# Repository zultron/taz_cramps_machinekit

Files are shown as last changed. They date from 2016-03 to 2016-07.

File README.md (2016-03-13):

# LulzBot TAZ 5 Machinekit Retrofit #

This repo contains initial documents for retrofitting a
[LulzBot TAZ 5][1] with [Machinekit][2] running on a
[Beaglebone black][3] with a [CRAMPS][4] V2.2 cape.  It is a work in
progress.

The retrofitted controller will fit in the original TAZ 5 controller
enclosure, and will be pin-compatible with the TAZ 5 harnesses.  The
wired LCD display will be replaced with the [Machineface][5] WiFi-connected
cross-platform remote control GUI.

[1]:  https://www.lulzbot.com/store/printers/lulzbot-taz-5
[2]:  http://machinekit.io
[3]:  http://beagleboard.org/black
[4]:  http://reprap.org/wiki/CRAMPS
[5]:  https://github.com/strahlex/Machineface

## Why? ##

My artist wife needs a 3D printer for her work, and [my company][6]
does, too.  Her friend and colleague loves her TAZ 5, and online
reviews are excellent.  It's open-source hardware, and I'm a founder
of the Machinekit project, an open-source machine control software
project.  3D printers are one type of machine that Machinekit can
control, and It sounded fun to source the parts and build it myself,
and at the same time retrofit the printer with a Beaglebone wearing a
CRAMPS cape (designed by Machinekit project co-founder Charles
Steinkuehler).

Why would anyone else want to do this?  The Beaglebone opens up the
possibilities of running web servers and network control protocols to
operate and monitor the printer remotely, just one example of
integrating sophisticated features not possible with the Arduino.
Machinekit isn't the easy route: while it's been moving ten-plus-ton
steel machines in industrial settings for over two decades, it's new
(like me) to the 3D printer world, and there are still a few remaining
challenges.  The more mature Octoprint may be a lower-effort means of
bringing the Beaglebone's power to the TAZ, and the hardware portion
of this retrofit should be identical.

[6]: http://dovetail-automata.com

## Electronics ##

The CRAMPS cape turns out to be an almost perfect fit for the TAZ-5.
It is designed for 24V, and can handle the TAZ's high power
requirements.  It can drive six motors, has a 15A heated bed FET, as
well as three high-power and two low-power FET outputs for extruders
and fans.  It has more than enough GPIO for limit switches and four
analog thermistor inputs.  To connect the TAZ-5 electronics, aside
from the control box internal harness changes, it also needs a 24V to
5V DC step-down converter to power the Beaglebone and micro blower.  A
board with a LM2596S or MP1584EN costs a few dollars on eBay, and are
tiny.

The motor and low-power FET connectors are Molex KK connectors instead
of the SL connectors the TAZ uses.  I changed the latched SL
connectors to non-latch versions for the limit switch and thermistor
inputs, since they are packed together on the CRAMPS in 2-row .100
headers, and the latch would interfere.  Other connections are
replaced with terminal blocks.

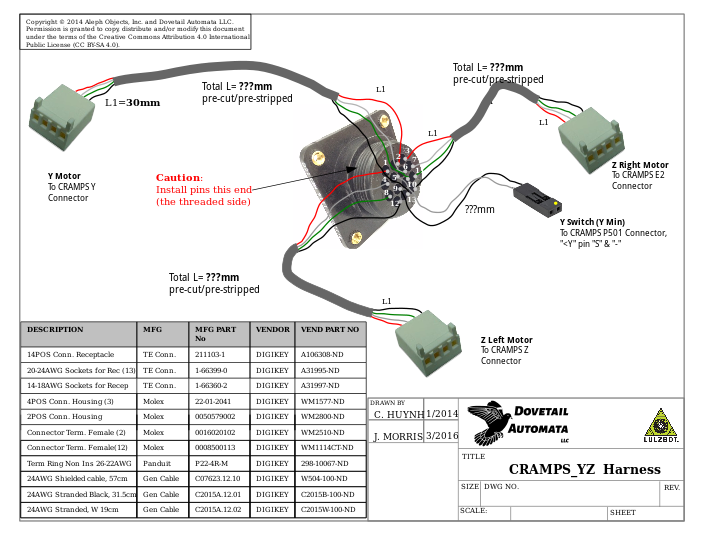
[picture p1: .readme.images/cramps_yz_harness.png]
CRAMPS YZ harness


See the `CRAMPS_*.svg` drawings in this repo for the changes needed to
control box internal harnesses.  If you open in inkscape, you can turn
the `CRAMPS` and `RAMBO` layers on and off to see exactly what
changed.

## Mechanical ##

The CRAMPS cape is about the same size as the RAMBO, but since it sits
atop the Beaglebone, the controller electronics are significantly
taller.  I still expect them to fit the original control box with just
a few millimeters clearance below the fan.

The Beaglebone's mounting holes are, of course, completely different.
A 3D printed part adapts the Beaglebone to the control box's threaded
inserts; see the `bbb_support_bracket.fcstd` FreeCAD model.  The
Beaglebone is attached with M3 flat head socket cap screws from the
bottom, screwing into a stand-off on top of the Beaglebone.  This is
screwed into the control box before the CRAMPS is added on top and
secured with more M3 screws into the stand-offs.  The adapter does not
yet include features to mount the DC step-down converter.

The current adapter cleverly allows access to the SD card through the
original controller box's USB port access hole.  The USB is blocked,
however, which means no WiFi.  I'm still debating whether to expose
the USB port instead (if that's possible) or whether to simply cut new
holes on the CNC mill, including extra holes for buttons, HDMI and
serial console.

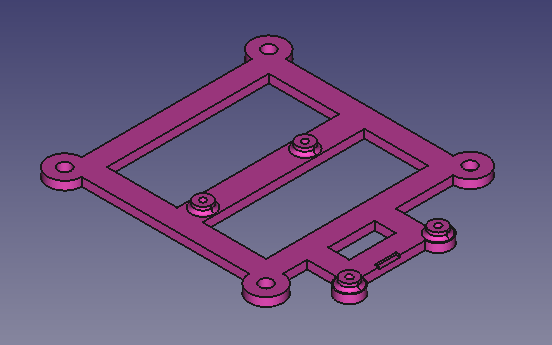
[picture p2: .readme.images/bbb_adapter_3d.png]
Beaglebone adapter


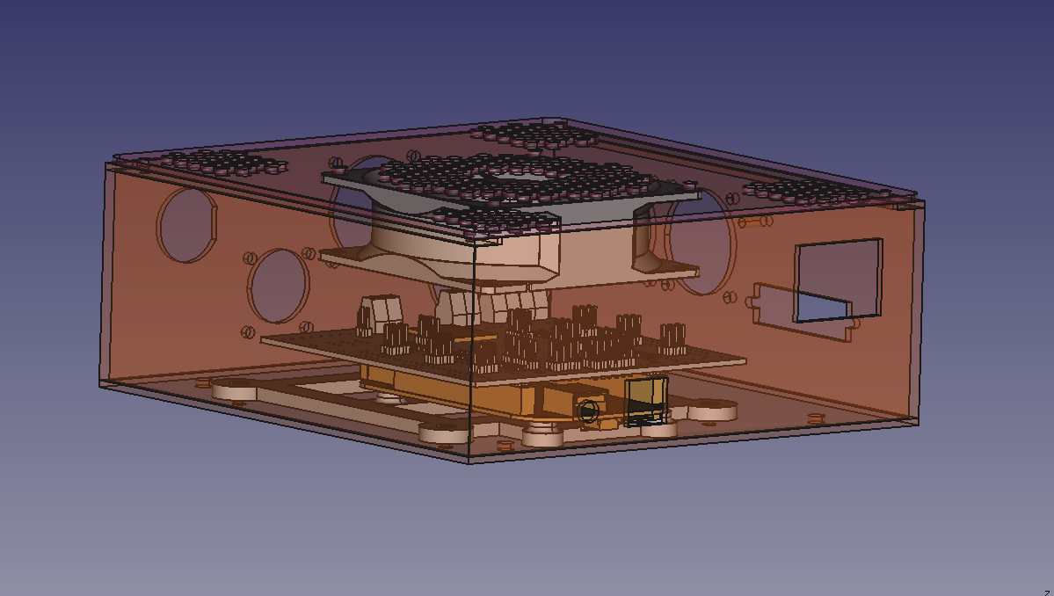
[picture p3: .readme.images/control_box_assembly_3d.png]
Control box assembly


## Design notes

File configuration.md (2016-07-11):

# Axes and geometry

The LulzBot TAZ-5 firmware `Configuration.h` file sets X and Y axes
to 100.5 steps/mm, Z to 1600 steps/mm and E0 at 850 steps/mm.  These
assume 1/16 microstepping, so set `JP201` through `JP206` shunts
accordingly.  Look up the settings for your model of driver, since
they are not all the same.  For example, for 1/16 microstepping,
shunts 1, 2 and 3 should be off, off and on, respectively, for DRV8825
drivers, and all on for A4988 drivers.

# Trimpot adjustment

http://reprap.org/wiki/A4988_vs_DRV8825_Chinese_Stepper_Driver_Boards#Trimpot_adjustment

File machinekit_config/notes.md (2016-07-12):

# Dual extruders

From [flexydually OHAI][fd-ohai]:

- Only one switchable fan
- [Duallie docs][duallie]
- Set temps:
  - Change tool head with `T0` (rear) and `T1` (front)
  - GUI has entry fields for extruder temp and bed (e.g. 240 and 100
    deg. C)
  - Wait until temp hits target, then click 'print' button
- Fan
  - Seems to be turned on per print; like coolant?
  - Apparently needs PWM to control speed?
  - `M106 P0 S255` sets fan 1 PWM on 100%
  - Repetier usage: `M106 P1 T45 H1:2` sets fan 2 to 'thermostatic'
    mode, on when either heater 1 or 2 is above 45 C.
  - `M107` is fan off (deprecated)
  - PWM period [may matter][fan-pwm]
  
After testing:
- Using one stepgen for both motors doesn't work; switching the
  extruder causes a 'joint following error'
- Instead, we probably need two stepgens wired to look like one to
  motion:
  - Two `position-fb` pins are added before going into `motor-pos-fb`
  - The deselected motor `position-cmd` input must be locked, and the
    difference of that and `motor-pos-cmd` coming out must be passed
    into the active `position-cmd` input
  - Probably needs a custom comp.

[fd-ohai]: https://ohai.lulzbot.com/project/lulzbot-taz-flexydually-tool-head-v2-installation/accessories/
[duallie]: http://devel.lulzbot.com/TAZ/accessories/javelin/
[fan-pwm]: https://groups.google.com/forum/#!topic/machinekit/BSLiZSQKoDQ

# 3D printer G code
- G codes at [reprap.org][rro-gcode]; note that 'Machinekit' is
  included in instruction implementation notes
- Some G codes in Machinekit `nc_files/` subdir:
  - `M104` set extruder temp
  - `M106 S255` fan off/on
- Daren Schwenke has a lot of M codes [implemented][ds-mcodes]

[rro-gcode]: http://reprap.org/wiki/G-code
[ds-mcodes]: https://github.com/Arcus-3d/Arcus-3D-M1

# Notes from TAZ configuration
- From the [TAZ firmware][TAZ-fw], `Marlin/Configuration.h`
- Heater limits:
  - They set e.g. `HEATER_0_MINTEMP` to 5, below which assume
    thermistor short/failure, and heater is disabled
  - `HEATER_0_MAXTEMP` is 250, then heater shut off; prevents
    accidental overheating
- Extruder PID terms:
  - Preset for 24V Buda 2.0:  Kp 6, Ki .3, Kd 125
  - `PID_MAX` 74; limits current to nozzle while PID is active (see
    `PID_FUNCTIONAL_RANGE` below); 255=full current
  - `PID_FUNCTIONAL_RANGE` 16; if the temperature difference between
    the target temperature and the actual temperature is more then
    `PID_FUNCTIONAL_RANGE` then the PID will be shut off and the
    heater will be set to min/max.
  - `PID_INTEGRAL_DRIVE_MAX` 70; limit for the integral term
  - `K1` 0.96; smoothing factor within the PID
  - `PID_dT` `((OVERSAMPLENR * 8.0)/(F_CPU / 64.0 / 256.0))` sampling
    period of the temperature routine
  - `EXTRUDE_MINTEMP` 120
- Bed PID terms:
  - Presets for 24V 360W silicone heater from NPH on 3mm borosilicate
    (TAZ 2.2+)
  - `MAX_BED_POWER` 206; limits duty cycle to bed; 255=full current
  - `DEFAULT_bedKp` 20; `DEFAULT_bedKi` 5; `DEFAULT_bedKd` 275
- Geometry:
  - `X_MAX_POS` 298; `Y_MAX_POS` 275; `Z_MAX_POS` 250
- Good stuff about auto bed leveling
- Homing speeds, mm/min:  50*60, 50*60, 8*60
- Axis steps per unit:   100.5,100.5,1600,850; all at 16 microsteps:
  - X/Y gearing: belt is 2mm pitch; gear is 16 teeth; (200 steps/rev)
    / (2mm/tooth * 16 teeth/rev) = 6.25 steps/mm; 1/16 microstepping?;
    Shunts: 1=lo; 2=lo; 3=hi
  - Z gearing: MTSBRK12-420-F7-R8-T9-Q8-S20-E5-FE0-FW7-FY1 screw is
    2mm pitch; (200 steps/rev) / (2mm/rev) = 100 steps/mm; 1/16
    microstepping; Shunts: 1=lo; 2=lo; 3=hi
  - Extruder: M8 hobbed bolt; est. 7mm at hob; gears 9:47; (47/9) *
    (200 steps/rev) / (22mm/rev) = 48 steps/mm; at 1/16 microstepping,
    760 steps/mm; estimate looks reasonable
- Max feedrate, mm/S:  800, 800, 8, 50
- Max accel:  9000,9000,100,10000 "max start speed for accelerated moves"
- Default accel:  500 mm/S^2 all joins max accel for printing moves
- Default retract accel:  3000 mm/S^2 max accel for retracts
- Offset of extruders, mm, X,Y:  E0 0,0; E1 0, -52
- Default jerk, mm/S: XY 8.0; Z 0.4; E 10.0; The speed change that
  does not require acceleration (i.e. the software might assume it can
  be done instantaneously)
- Preheat constants:
  - PLA:  hotend temp 180; hpb temp 50; fan speed 0/255;
  - ABS:  hotend temp 230; hpb temp 85; fan speed 0/255;
- More stuff in `Configuration_adv.h`
- Also `thermistortables.h`

[TAZ-fw]: http://devel.lulzbot.com/TAZ/Holly/software/2014Q3_rB/Marlin/Marlin-2014Q3_rB.tar

# INI file
INI [docs][1]

[1]: http://www.machinekit.io/docs/config/ini_config/

## Steps/mm

From [flexydually OHAI][fd-ohai]:

- X 100.5
- Y 100.5
- Z 1600.0
- Extruder:  configurable, from label
- Retract 3000

## Homing

    HOME_SEARCH_VEL =       -5.0
    HOME_LATCH_VEL =        5.0

# HAL file

- [Pin mappings][2]

[2]: https://drive.google.com/open?id=1xLqDcoijuftPpDJuLmIFQLNdOEL-pKPV24phtdy3Io8

- `hal_temp_bbb` broken; high pin limit needs to be set to 6:

        $ halcmd loadusr -Wn Therm hal_temp_bbb -n Therm -c \
	      04:epcos_B57560G1104,05:epcos_B57560G1104,06:epcos_B57560G1104 -b CRAMPS
        Pin not available

# Testing

## Connector diagram

        Enclosure connector layouts
        Rear:        Top:
        +-----+      +-----+
        | X   | XZ   | X   | Ext1
        |   X | YZ   | X   | Ext2
        | x   | Bed  |   | | D Sub
        |   o | Pwr  |   | | (Empty)
        +-----+      +-----+

        Large 'X' connector pin numbering
             +-+ Large notch
          3 X X X 1
         7 X X X X 4
        11 X X X X 8
         13 X X X 12

        Small 'x' connector pin numbering
           +-+ Large notch
          1 X
         3 X X 2
          4 X

        Pololu header pin numbering
        1 .    . 16
          .    .
          .    .    .
          .    .  | . (Motor conn.)
          .    .  | .
          .    .    .
          .    .
        8 .    . 9

## Power continuity
- Unplug power and printer
- Check continuity between power connector red wires and power switch
- With power switch on, check continuity between power connector red
  wires and:
  - Wire 1:  Motor and extruder power `+` terminals
  - Wire 2:  Bed power `+` terminal
- Repeat with switch off, verifying no continuity
- Check continuity between power connector yellow wires and:
  - Wire 1:  Motor, extruder and system power `-` terminals
  - Wire 2:  Bed power `-` terminal
- 5V checks FIXME
- E2 MOSFET module checks FIXME

## Power voltage
- Unplug wire from 5V converter module OUT+ to CRAMPS 5V system power
- Remove three fuses
- Remove Pololu modules
- Turn enclosure power switch off
- Plug in power supply
- Turn power supply switch on
- Check for 24V DC between power connector red and yellow wires
- Check for 0V DC at motor and bed power `+` terminals
- Turn enclosure power switch on
- Check for 24V DC at motor, extruder and bed power `+` terminals, and
  5V converter module `IN+`
- Check for 5V DC at 5V converter module OUT
- Check for 0V DC at Motor, extruder and bed power `-` terminals
- Turn enclosure power switch off
- Replace three fuses, with 15A fuse in middle holder
- Turn enclosure power switch on
- Check for 24V DC at P401 Bed Heater and P405 E0 power out `+` terminals
- Turn enclosure power switch off
- Plug wire from 5V converter module OUT+ to CRAMPS 5V system power
- Turn enclosure power switch on
- Verify `BB ON` LED is lit
- Check for 5V DC at P404 5V System Power terminal

## Limit switches and motor step/dir

- Setup
  - Disconnect control box cables except for power
  - Remove Pololu/stepper driver boards
  - Power on, boot up, `ssh -X` in
  - `cd` to this directory
  - `linuxcnc CRAMPS.ini &`; wait for Axis GUI to appear
- Test each limit switch:
  - Run `halcmd show signal limit-*-min`, where `*` is `x`, `y` or
	`z`; verify the value is false
  - Short the correct pins on the correct connector
	- X:  XZ connector pins 6 and 10
	- Y:  YZ connector pins 5 and 9
	- Z:  XZ connector pins 9 and 13
  - Rerun the same command; verify the value is true
- Test enable signal and each motor step and dir signals:
  - In Axis GUI, toggle estop and power buttons
  - On the "Manual Control" tab, select the axis to test, `X`, `Y`,
    `Z` or `A`
  - Put a volt meter on `DIR` pin 8 for the CRAMPS Pololu connector
    corresponding to the axis:  `X` = `X`; `Y` = `Y`; `Z` = `Z` and
    `E2`; `A` = extruder (see below); use any ground, or pin 9
  - With the jog increment set to continuous, jog with the `+` and `-`
    buttons, verifying the voltage goes between 0V and 3.3V
  - Put the volt meter on the `Step` pin 7, and verify the voltage
    increases some small amount above 0V; try increasing the "Jog
    Speed" slider for better results
  - For the `A` axis, test as above for the default `E0` pololu socket
    first; then run `halcmd sets extruder.select 1` and repeat for the
    `E1` socket
- Test ESTOP:
  - Remove the shunt from CRAMPS `ESTOP` connector P302; verify that
    the machine has reset in Axis; verify the CRAMPS `ESTOP` LED
    turns on
  - Replace the shunt; in Axis, toggle ESTOP and machine power;
    verify the CRAMPS `ESTOP` LED turns off
- Test machine power signal:
  - Toggle machine power button in Axis; verify `STATUS` LED lights
    with power on
- Test bed and extruder heater FETs:
  - Machine power must be on in Axis
  - Run `halcmd show signal | grep '*.\(temp\|heater\)'`, where `*` is
    `e0`, `e1` or `bed`
  - For E1, run `halcmd sets e1.ini.enable 1`
  - Choose a value much lower than `*.temp.meas`, e.g. -500, and set
    the PID with `halcmd sets *.temp.set -500`
  - Re-run the above `halcmd show signal` command, and verify that the
    `*.heater` signal is 0
  - Verify 24VDC voltage at FET connector `-` terminal
  - Verify FET LED is off
  - Choose a value much higher than `*.temp.meas`, e.g. 500, and set
    the PID with `halcmd sets *.temp.set 500`
  - Re-run the above `halcmd show signal` command, and verify that the
    `*.heater` signal is a positive number
  - Verify 0VDC voltage at FET connector `-` terminal
  - Verify FET LED is on
  - For safety, reset the PID with `halcmd sets *.temp.set 0` after
    testing an individual FET, and `halcmd sets e1.ini.enable 0` after
    testing the E1 FET
- Test bed and extruder heater thermistors: FIXME
- Test extruder fan:
  - Machine power must be on in Axis
  - Run `halcmd sets fan.speed.set 0`
  - Verify 24VDC voltage at E2 FET connector `-` terminal
  - Verify E2 FET LED is off
  - Run `halcmd sets fan.speed.set 255`
  - Verify <24VDC voltage at E2 FET connector `-` terminal
  - Verify E2 FET LED is on (perhaps pulsing)

# Bring up
- Set microstepping shunts to 16V for each motor:
  - For DRV8825, shunts 1 and 2 should be off; shunt 3 should be on
- Set Pololu current limit trimpot
  - Disconnect motors and power up controller
  - Measure Vref at driver current limit trim pot
  - Adjust trim pot according to driver and motor rated current
    - Example motor current ratings:
      - Stock TAZ SY42STH47-1504A motors [rated 1.5A][taz-motor-ds]
	  - 17HS16-2004S1 motors rated 2A
    - Determine how to set Vref for your driver
	  - [DRV8825][pololu-drv8825]:  current = 2 * Vref; Vref = 0.75V
        for stock TAZ motors
    - Set current; [helpful video][pololu-trim-vid]
      - Attach volt meter to screwdriver and adjust trim pot to Vref

[taz-motor-ds]: https://download.lulzbot.com/AO-100/hardware/electronics/spec_sheets/SY42STH47-1504A_stepperMotors.pdf
[pololu-trim-vid]: https://www.youtube.com/watch?v=89BHS9hfSUk
[pololu-drv8825]: https://www.pololu.com/product/2133

# Machineface
- Daren's [configs][ds-mcodes]; see `Arcus-3D-M1.qbs`, `launcher.ini`,
  `run.py`, `storage.ini`

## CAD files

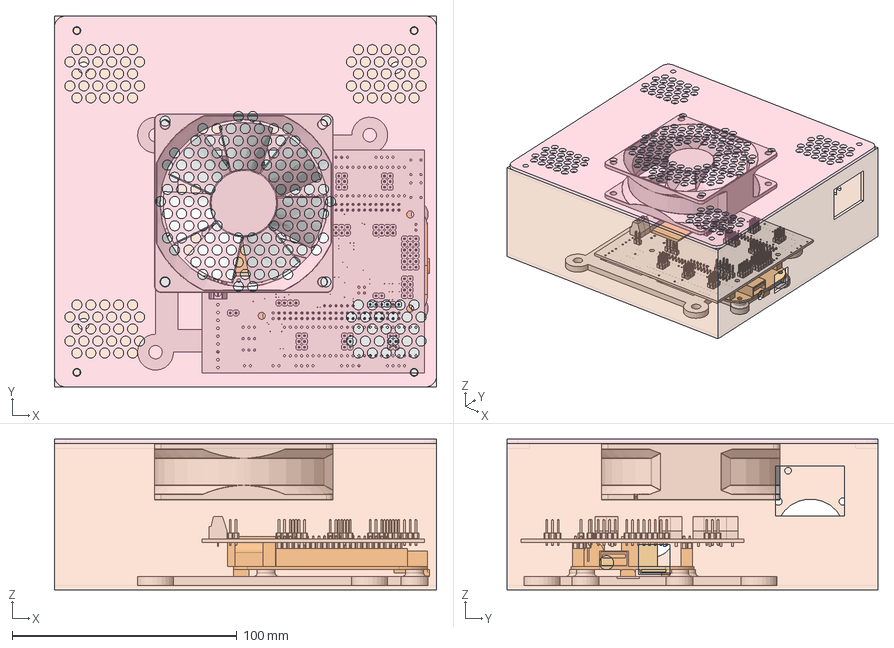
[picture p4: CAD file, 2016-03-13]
mechanical/control_box_assembly.fcstd
170.0 x 165.0 x 67.0 mm
control_box_enclosure
beaglebone_black
bbb_support_bracket
CRAMPS_3D_step1_01
_0mm_fan_igs1_01
electronics_cover_revA_fc0_1_01

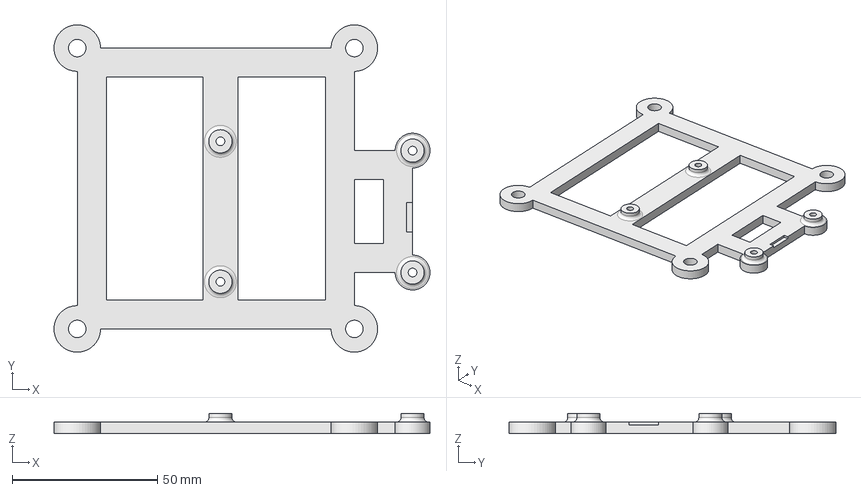
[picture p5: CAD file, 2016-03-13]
mechanical/bbb_support_bracket.fcstd
129.2 x 112.5 x 7.00 mm

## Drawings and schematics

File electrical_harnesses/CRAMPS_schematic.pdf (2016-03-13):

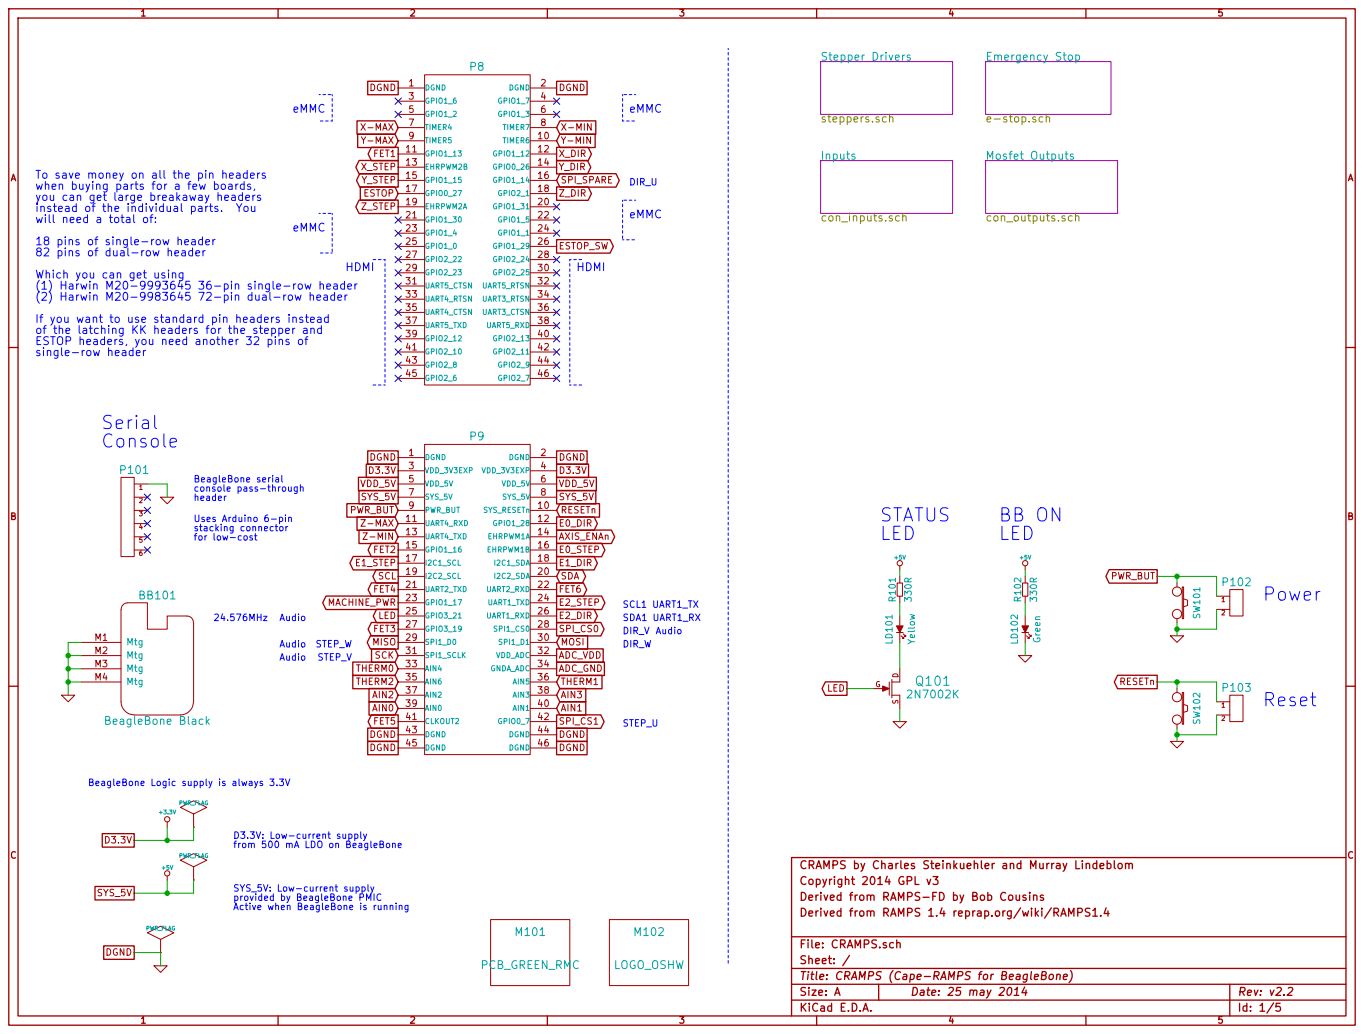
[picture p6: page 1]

To save money on all the pin headers
when buying parts for a few boards,
you can get large breakaway headers
instead of the individual parts. You will need a total of: 18 pins of single-row header

82 pins of dual-row header
Which you can get using
(1) Harwin M20-9993645 36-pin single-row header
(2) Harwin M20-9983645 72-pin dual-row header
If you want to use standard pin headers instead
of the latching KK headers for the stepper and
ESTOP headers, you need another 32 pins of

BeagleBone Logic supply is always 3.3V

D3.3V: Low-current supply
from 500 mA LDO on BeagleBone

CRAMPS by Charles Steinkuehler and Murray Lindeblom
Copyright 2014 GPL v3
Derived from RAMPS-FD by Bob Cousins
Derived from RAMPS 1.4 reprap.org/wiki/RAMPS1.4

provided by BeagleBone PMIC
Active when BeagleBone is running

File: CRAMPS.sch
Sheet: /
Title: CRAMPS (Cape-RAMPS for BeagleBone)
KiCad E.D.A.

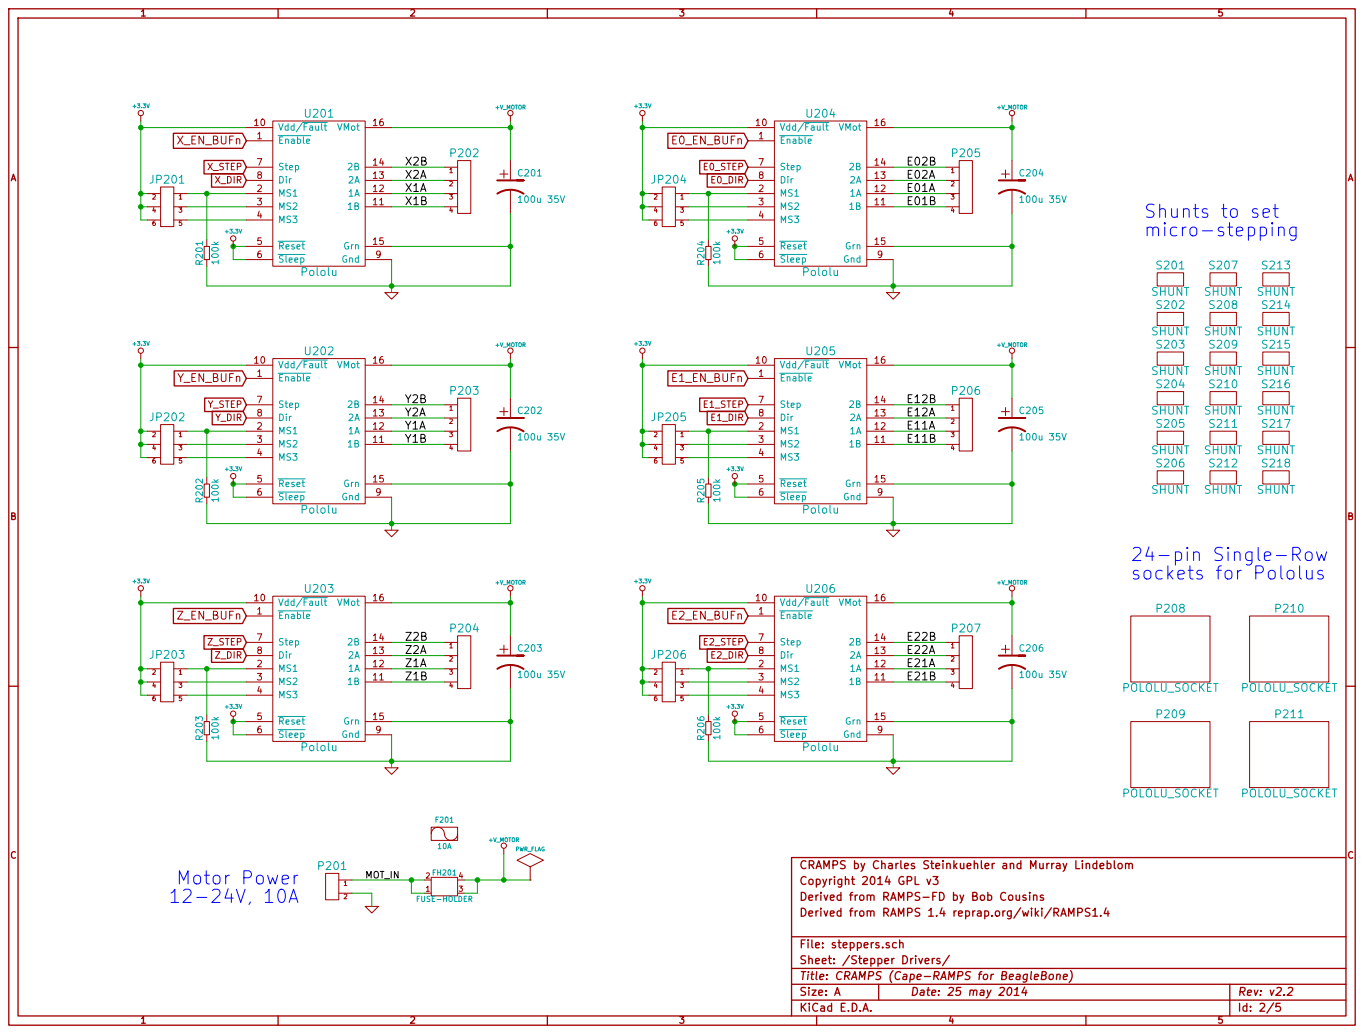
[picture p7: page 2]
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

File: steppers.sch
Sheet: /Stepper Drivers/
Title: CRAMPS (Cape-RAMPS for BeagleBone)

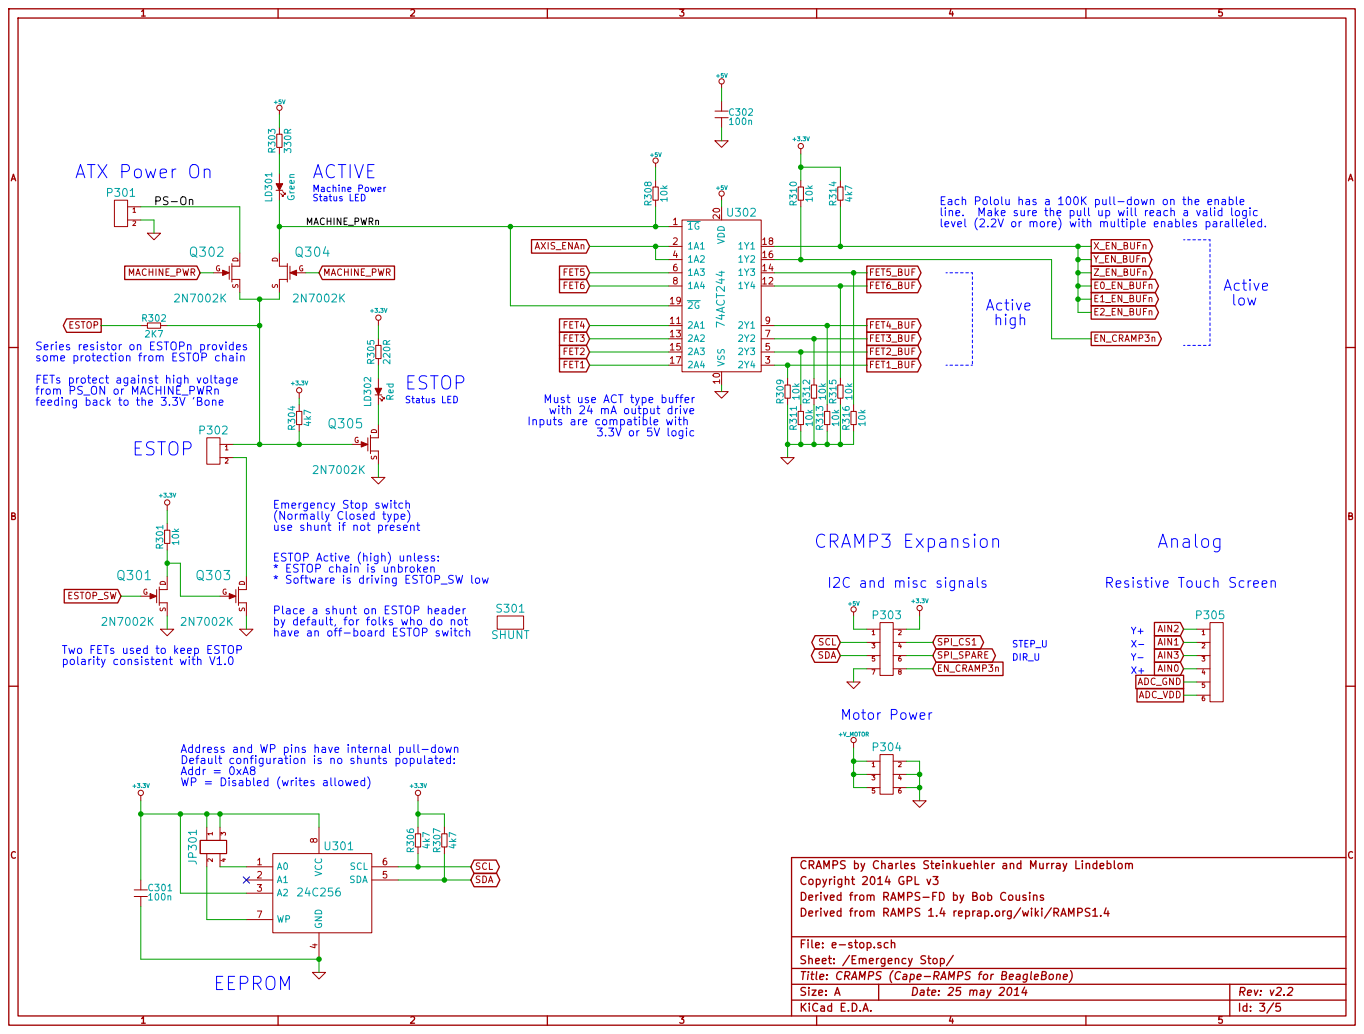
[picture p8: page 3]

Each Pololu has a 100K pull-down on the enable
line. Make sure the pull up will reach a valid logic

level (2.2V or more) with multiple enables paralleled. ESTOP

Series resistor on ESTOPn provides
some protection from ESTOP chain
FETs protect against high voltage
from PS_ON or MACHINE_PWRn
feeding back to the 3.3V 'Bone

Must use ACT type buffer
with 24 mA output drive
Inputs are compatible with

ESTOP Active (high) unless:
* ESTOP chain is unbroken
* Software is driving ESTOP_SW low

Place a shunt on ESTOP header
by default, for folks who do not
have an off-board ESTOP switch

Two FETs used to keep ESTOP
polarity consistent with V1.0

100n Address and WP pins have internal pull-down
Default configuration is no shunts populated: Addr = 0xA8 WP = Disabled (writes allowed)

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

File: e-stop.sch
Sheet: /Emergency Stop/
Title: CRAMPS (Cape-RAMPS for BeagleBone)

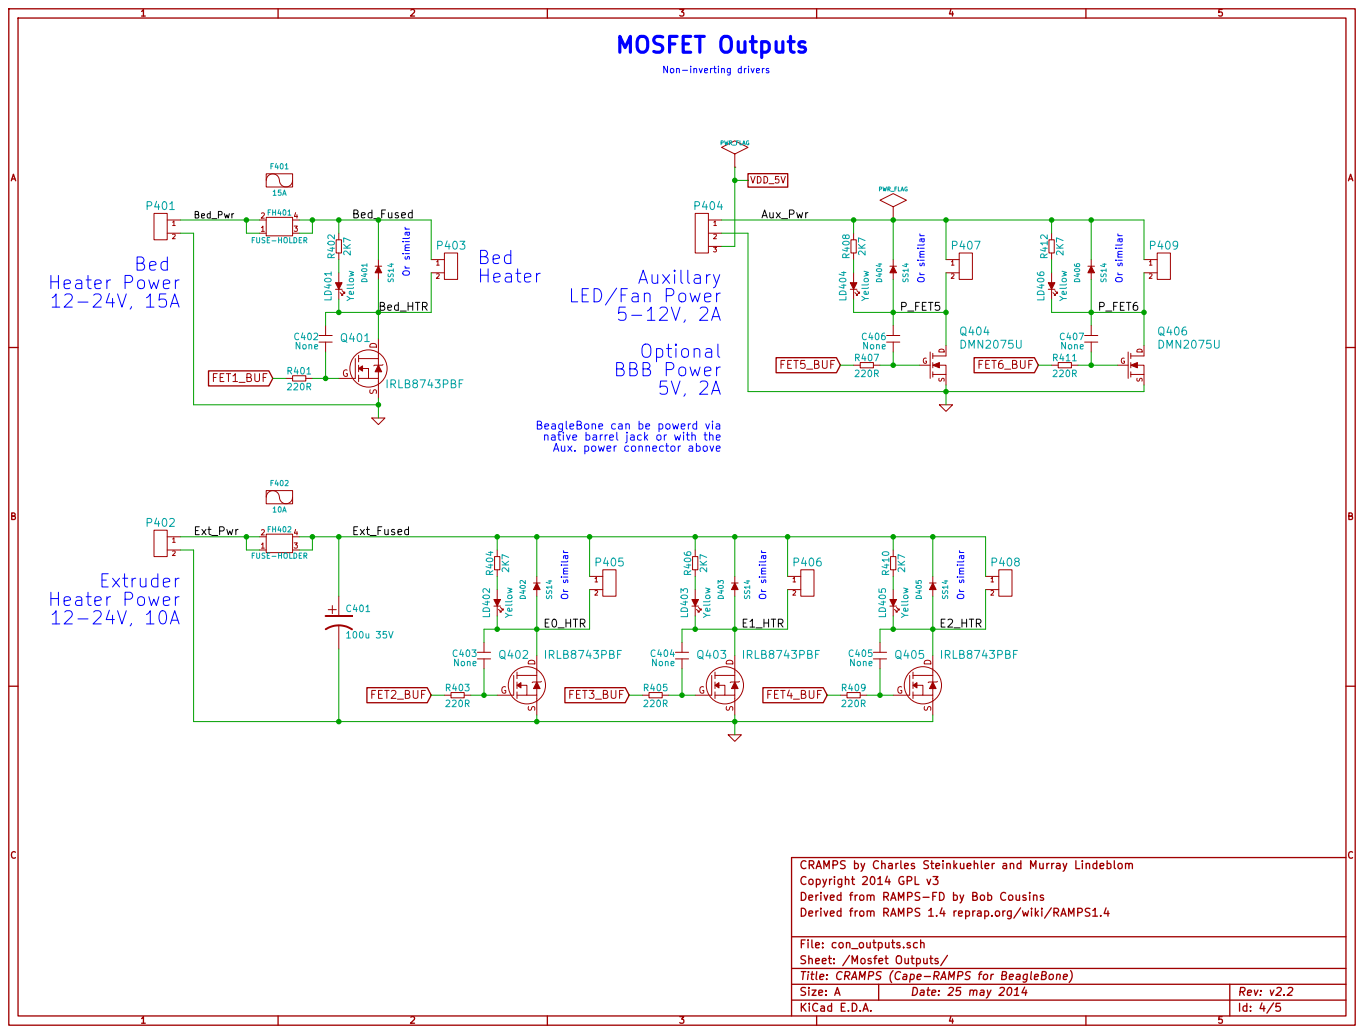
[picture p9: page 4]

BeagleBone can be powerd via
native barrel jack or with the
Aux. power connector above

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

File: con_outputs.sch
Sheet: /Mosfet Outputs/
Title: CRAMPS (Cape-RAMPS for BeagleBone)

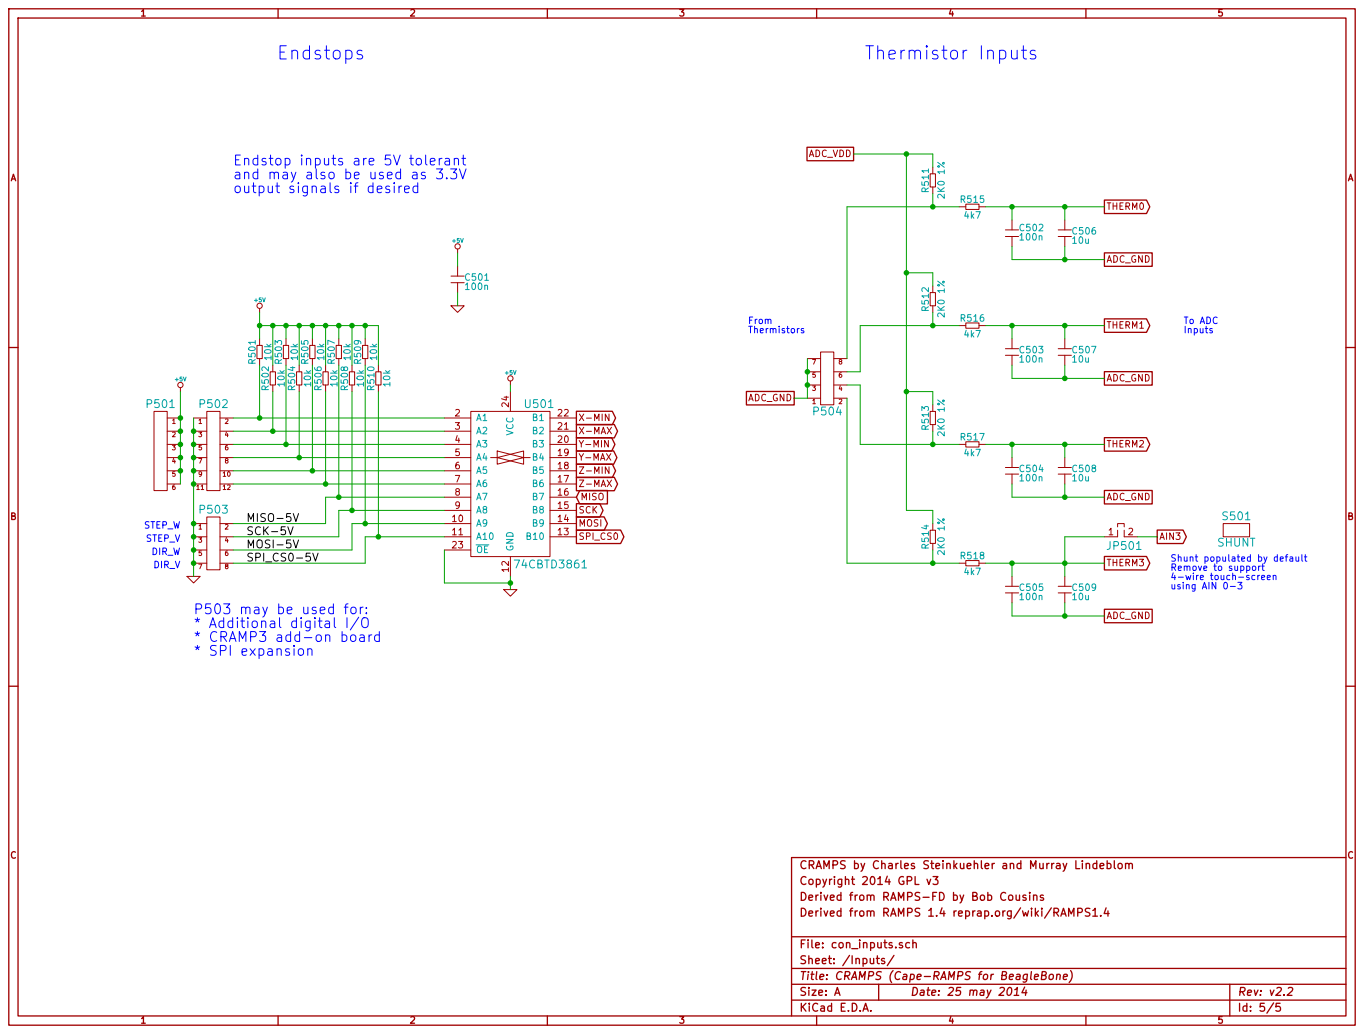
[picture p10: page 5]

100n Endstop inputs are 5V tolerant
and may also be used as 3.3V
output signals if desired

1 | 2 SCK-5V
3 | 4 MOSI-5V
5 | 6 SPI_CS0-5V

Remove to support 4-wire touch-screen

P503 may be used for:
* Additional digital I/O
* CRAMP3 add-on board
* SPI expansion

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

File: con_inputs.sch
Sheet: /Inputs/
Title: CRAMPS (Cape-RAMPS for BeagleBone)

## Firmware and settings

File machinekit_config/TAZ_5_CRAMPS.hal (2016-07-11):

# #######################################
#
# HAL file for TAZ-5 BeagleBone + CRAMPS cape retrofit
#
# Derived from example CRAMPS config
#
# See https://github.com/zultron/taz_machinekit_retrofit
#
# Pin assignments are documented in setup.sh
#
# ########################################

# Launch the setup script to make sure hardware setup looks good
loadusr -w ./setup.sh


# ###################################
# Core EMC/HAL Loads
# ###################################

# motion controller, get name and thread periods from ini file
# trajectory planner
loadrt tp
loadrt trivkins
loadrt [EMCMOT]EMCMOT servo_period_nsec=[EMCMOT]SERVO_PERIOD num_joints=[TRAJ]AXES tp=tp kins=trivkins

# gpio drivers
loadrt hal_bb_gpio output_pins=826,914,921,923,925,941 input_pins=808,810,817,913

# PRU driver with 5 stepgens and 4 pwmgens
#     stepgen timings:  max(XY,Z,E) = max(960*100.5, 9.6*1600, 60*860) =
#         max(96480, 15360, 51600) = 96480 ~= 100k steps/S; 1 step = 2 periods (1 hi, 1 lo);
#         100k steps/S * 2 periods/step = 200k periods/S; 1/200kHz = 5uS/period
loadrt hal_pru_generic prucode=$(HAL_RTMOD_DIR)/xenomai/pru_generic.bin pru=0 num_stepgens=5 num_pwmgens=4 halname=hpg pru_period=5000
setp hpg.pwmgen.00.pwm_period       10000000

# PIDs with input limits for heaters
loadrt pid count=3
loadrt limit1 count=3

# Multiplexers and logic for dual extruder
loadrt mux_generic config="uu2,uu2,ff2"
loadrt and2 count=1

# Thermistor ADC values for PWM
#
# 24V silicone heater [3]: Honeywell 100k [4], [5]
# Hexagon Hot End thermistor [1]: EPCOS 100k [2]
#    
# [1]: https://www.lulzbot.com/store/parts/100k-epcos-thermistor
# [2]: http://www.epcos.com/inf/50/db/ntc_09/Glass_enc_Sensors__B57560__G560__G1560.pdf
# [3]: https://www.lulzbot.com/store/parts/24v-silicone-heater
# [4]: https://www.lulzbot.com/store/parts/100k-honeywell-axial-thermistor
# [5]: http://media.digikey.com/pdf/Data%20Sheets/Honeywell%20Sensing%20&%20Control%20PDFs/135-104LAG-J01.pdf
loadusr -Wn Therm hal_temp_bbb -n Therm -c 04:epcos_B57560G1104,05:epcos_B57560G1104,06:epcos_B57560G1104 -b CRAMPS

# ################################################
# THREADS
# ################################################

addf hpg.capture-position           servo-thread
addf bb_gpio.read                   servo-thread
addf motion-command-handler         servo-thread
addf motion-controller              servo-thread
addf pid.0.do-pid-calcs             servo-thread
addf pid.1.do-pid-calcs             servo-thread
addf pid.2.do-pid-calcs             servo-thread
addf limit1.0                       servo-thread
addf limit1.1                       servo-thread
addf limit1.2                       servo-thread
addf mux-gen.00                     servo-thread
addf mux-gen.01                     servo-thread
addf mux-gen.02                     servo-thread
addf and2.0                         servo-thread
addf hpg.update                     servo-thread
addf bb_gpio.write                  servo-thread


# ################
# X [0] Axis
# ################
#
# Attached to CRAMPS X motor connector with hpg.stepgen.00

# axis enable chain
net emcmot.00.enable                => hpg.stepgen.00.enable
sets emcmot.00.enable               FALSE
net emcmot.00.enable                <= axis.0.amp-enable-out

# position command
net emcmot.00.pos-cmd               <= axis.0.motor-pos-cmd
net emcmot.00.pos-cmd               => hpg.stepgen.00.position-cmd

# position feedback
net motor.00.pos-fb                 <= hpg.stepgen.00.position-fb
net motor.00.pos-fb                 => axis.0.motor-pos-fb

# timing parameters
setp hpg.stepgen.00.dirsetup        [AXIS_0]DIRSETUP
setp hpg.stepgen.00.dirhold         [AXIS_0]DIRHOLD
setp hpg.stepgen.00.steplen         [AXIS_0]STEPLEN
setp hpg.stepgen.00.stepspace       [AXIS_0]STEPSPACE
setp hpg.stepgen.00.position-scale  [AXIS_0]SCALE
setp hpg.stepgen.00.maxvel          [AXIS_0]STEPGEN_MAX_VEL
setp hpg.stepgen.00.maxaccel        [AXIS_0]STEPGEN_MAX_ACC
setp hpg.stepgen.00.steppin         813 # 0x32D
setp hpg.stepgen.00.dirpin          812 # 0x32C

# Limit switch
net limit-x-min                     <= bb_gpio.p8.in-08
setp bb_gpio.p8.in-08.invert        1
net limit-x-min                     => axis.0.home-sw-in
net limit-x-min                     => axis.0.neg-lim-sw-in


# ################
# Y [1] Axis
# ################
#
# Attached to CRAMPS Y motor connector with hpg.stepgen.01

# axis enable chain
net emcmot.01.enable                => hpg.stepgen.01.enable
sets emcmot.01.enable               FALSE
net emcmot.01.enable                <= axis.1.amp-enable-out

# position command
net emcmot.01.pos-cmd               <= axis.1.motor-pos-cmd
net emcmot.01.pos-cmd               => hpg.stepgen.01.position-cmd

# position feedback
net motor.01.pos-fb                 <= hpg.stepgen.01.position-fb
net motor.01.pos-fb                 => axis.1.motor-pos-fb

# motor parameters
setp hpg.stepgen.01.dirsetup        [AXIS_1]DIRSETUP
setp hpg.stepgen.01.dirhold         [AXIS_1]DIRHOLD
setp hpg.stepgen.01.steplen         [AXIS_1]STEPLEN
setp hpg.stepgen.01.stepspace       [AXIS_1]STEPSPACE
setp hpg.stepgen.01.position-scale  [AXIS_1]SCALE
setp hpg.stepgen.01.maxvel          [AXIS_1]STEPGEN_MAX_VEL
setp hpg.stepgen.01.maxaccel        [AXIS_1]STEPGEN_MAX_ACC
setp hpg.stepgen.01.steppin         815 # 0x32F
setp hpg.stepgen.01.dirpin          814 # 0x32E

# Limit switch
net limit-y-min                     <= bb_gpio.p8.in-10
setp bb_gpio.p8.in-10.invert        1
net limit-y-min                     => axis.1.home-sw-in
net limit-y-min                     => axis.1.neg-lim-sw-in


# ################
# Z [2] Axis
# ################

# The TAZ-5 Z axis has two motors, the right on the Z connector driven
# by hpg.stepgen.02 and the left on the E2 connector driven by
# hpg.stepgen.03, and a shared limit switch.  Instead of using
# gantrykins or the gantry HAL component, simply tie both joints'
# stepgens together.

# axis enable chain
net emcmot.02.enable                => hpg.stepgen.02.enable
net emcmot.02.enable                => hpg.stepgen.03.enable
sets emcmot.02.enable               FALSE
net emcmot.02.enable                <= axis.2.amp-enable-out

# position command
net emcmot.02.pos-cmd               <= axis.2.motor-pos-cmd
net emcmot.02.pos-cmd               => hpg.stepgen.02.position-cmd
net emcmot.02.pos-cmd               => hpg.stepgen.03.position-cmd

# position feedback
net motor.02.pos-fb                 => axis.2.motor-pos-fb
# (feedback supplied by right motor)
net motor.02.pos-fb                 <= hpg.stepgen.02.position-fb

# Right motor parameters
setp hpg.stepgen.02.dirsetup        [AXIS_2]DIRSETUP
setp hpg.stepgen.02.dirhold         [AXIS_2]DIRHOLD
setp hpg.stepgen.02.steplen         [AXIS_2]STEPLEN
setp hpg.stepgen.02.stepspace       [AXIS_2]STEPSPACE
setp hpg.stepgen.02.position-scale  [AXIS_2]SCALE
setp hpg.stepgen.02.maxvel          [AXIS_2]STEPGEN_MAX_VEL
setp hpg.stepgen.02.maxaccel        [AXIS_2]STEPGEN_MAX_ACC
setp hpg.stepgen.02.steppin         819 # 0x333
setp hpg.stepgen.02.dirpin          818 # 0x332

# Left motor parameters
setp hpg.stepgen.03.dirsetup        [AXIS_2]DIRSETUP
setp hpg.stepgen.03.dirhold         [AXIS_2]DIRHOLD
setp hpg.stepgen.03.steplen         [AXIS_2]STEPLEN
setp hpg.stepgen.03.stepspace       [AXIS_2]STEPSPACE
setp hpg.stepgen.03.position-scale  [AXIS_2]SCALE
setp hpg.stepgen.03.maxvel          [AXIS_2]STEPGEN_MAX_VEL
setp hpg.stepgen.03.maxaccel        [AXIS_2]STEPGEN_MAX_ACC
setp hpg.stepgen.03.steppin         924 # 0x39C
setp hpg.stepgen.03.dirpin          926 # 0x39E

# Limit switch
net limit-z-min                     <= bb_gpio.p9.in-13
setp bb_gpio.p9.in-13.invert        1
net limit-z-min                     => axis.2.home-sw-in
net limit-z-min                     => axis.2.neg-lim-sw-in


# ################
# E1 enable logic
# ################

# Logically 'and' .ini file param and motion enable to e1.enable signal
net e1.ini.enable                   => and2.0.in0
sets e1.ini.enable                  [TAZ_5]DUAL_EXTRUDER_ENABLE
net emcmot.00.enable                => and2.0.in1
net e1.enable                       <= and2.0.out

# ################
# A/Extruder [3] Axis
# ################

# Two MUXed extruders are selected by setting the extruder.select
# signal to 0 or 1

# The two extruder motors share hpg.stepgen.04 under the assumption
# that only one will move at any time.  Step and dir pin parameters
# are reassigned during M6 execution.

# E0 motor on P205 E0 motor connector, with step on p9.16 and dir on
# p9.12

# E1 Motor on P206 E1 motor connector, with step on p9.17 and dir on
# p9.18

# axis enable chain
net emcmot.03.enable                => hpg.stepgen.04.enable
sets emcmot.03.enable               FALSE
net emcmot.03.enable                <= axis.3.amp-enable-out
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

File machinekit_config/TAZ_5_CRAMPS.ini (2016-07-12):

[TAZ_5]
# Dual extruder:  0 to disable, 1 to enable
DUAL_EXTRUDER_ENABLE = 0
# Extruder steps-per-mm
E0_ESTEPS = 850
E1_ESTEPS = 1
# Max acceleration for retracts, mm/S^2
RETRACT_ACCEL = 3000
# Extruder offsets, mm
E0_OFFSET_X = 0.0
E0_OFFSET_Y = 0.0
E1_OFFSET_X = 0.0
E1_OFFSET_Y = -52.0
# Preheat constants for hot end (deg. C), heated print bed (deg. C),
# fan speed (0..255), and for PLA or ABS
PREHEAT_PLA_TEMP_HOTEND = 180
PREHEAT_PLA_TEMP_HPB = 50
PREHEAT_PLA_FAN_SPEED = 0
PREHEAT_ABS_TEMP_HOTEND = 230
PREHEAT_ABS_TEMP_HPB = 85
PREHEAT_ABS_FAN_SPEED = 0

# Tool head selector (unused; should replace DUAL_EXTRUDER_ENABLE):
# 0:  Single extruder V2
# 1:  Flexystruder V2
# 2:  Dual extruder V2
# 3:  FlexyDually V2
TOOL_HEAD = 0

[EMC]

# Name of machine, for use with display, etc.
MACHINE =               TAZ_5_CRAMPS

# Debug level, 0 means no messages. See src/emc/nml_int/emcglb.h for others
#DEBUG =                0x00000003
#DEBUG =                0x00000007
DEBUG = 0




[DISPLAY]

# Name of display program, e.g., tkemc
DISPLAY = axis
#DISPLAY = mkwrapper

# Cycle time, in seconds, that display will sleep between polls
CYCLE_TIME =            0.200

# Path to help file
HELP_FILE =             tklinucnc.txt

# Initial display setting for position, RELATIVE or MACHINE
POSITION_OFFSET =       RELATIVE

# Initial display setting for position, COMMANDED or ACTUAL
POSITION_FEEDBACK =     ACTUAL

# Highest value that will be allowed for feed override, 1.0 = 100%
MAX_FEED_OVERRIDE =     1.5

# Prefix to be used
#PROGRAM_PREFIX = ../../../nc_files/

# Introductory graphic
INTRO_GRAPHIC =         machinekit.gif
INTRO_TIME =            5

# Increments for the JOG section
INCREMENTS = 0.01 0.1 1

MIN_VELOCITY = 1.0

PYVCP = 3D.Temps.panel.xml

[FILTER]
PROGRAM_EXTENSION = .png,.gif,.jpg Grayscale Depth Image
PROGRAM_EXTENSION = .py Python Script
PROGRAM_EXTENSION = .gcode RepRap Flavour GCode
png = image-to-gcode
gif = image-to-gcode
jpg = image-to-gcode
py = python
gcode = gcode-to-ngc

[TASK]

# Name of task controller program, e.g., milltask
TASK =                  milltask

# Cycle time, in seconds, that task controller will sleep between polls
CYCLE_TIME =            0.010




[RS274NGC]

# File containing interpreter variables
PARAMETER_FILE =        pru-stepper.var

# subroutine path for the custom FDM printing .ngc files used for remapping
# use directory in config path until more suitable location. this w.r.t the
# fact that not every machine will have an extruder and/or fan
#SUBROUTINE_PATH = /usr/share/linuxcnc/ncfiles/remap-subroutines/fdm
SUBROUTINE_PATH = subroutines

# remapping Machinekit FDM GCodes
REMAP=G22 modalgroup=1 ngc=g22
REMAP=G23 modalgroup=1 ngc=g23
REMAP=G28 modalgroup=1 argspec=xyza ngc=g28
REMAP=G29 modalgroup=1 ngc=g29
REMAP=G29.1 modalgroup=1 argspec=xyz ngc=g29_1
REMAP=G29.2 modalgroup=1 argspec=xyz ngc=g29_2
REMAP=G30 modalgroup=1 argspec=pxy ngc=g30
REMAP=G70 modalgroup=1 ngc=g70
REMAP=G71 modalgroup=1 ngc=g71
REMAP=G72 modalgroup=1 ngc=g72
REMAP=G79 modalgroup=1 ngc=g79
REMAP=M104 modalgroup=10 argspec=iPt ngc=m104
REMAP=M106 modalgroup=10 argspec=iPt ngc=m106
REMAP=M107 modalgroup=10 argspec=it ngc=m107
REMAP=M109 modalgroup=10 argspec=tP ngc=m109
REMAP=M140 modalgroup=10 argspec=iP ngc=m140
REMAP=M141 modalgroup=10 argspec=iP ngc=m141
REMAP=M162 modalgroup=10 argspec=P ngc=m162
REMAP=M163 modalgroup=10 argspec=SP ngc=m163
REMAP=M190 modalgroup=10 argspec=P ngc=m190
REMAP=M191 modalgroup=10 argspec=P ngc=m191
REMAP=M200 modalgroup=10 argspec=D ngc=m200
REMAP=M226 modalgroup=10 ngc=m226
REMAP=M280 modalgroup=10 argspec=itP ngc=m280
REMAP=M300 modalgroup=10 argspec=iqP ngc=m300
REMAP=M400 modalgroup=10 ngc=m400
REMAP=M420 modalgroup=10 argspec=itredp ngc=m420
REMAP=M700 modalgroup=10 argspec=iP ngc=m700
#REMAP=M601 modalgroup=10 argspec=SP ngc=m601
REMAP=M750 modalgroup=10 ngc=m750

# enable ini parameter passing, e.g. `#1 = #<_ini[AXIS_0]PGAIN>`
FEATURES = 4

[EMCMOT]

EMCMOT =                motmod

# Timeout for comm to emcmot, in seconds
COMM_TIMEOUT =          1.0

# Interval between tries to emcmot, in seconds
COMM_WAIT =             0.010

# Servo task period, in nanoseconds
SERVO_PERIOD =          1000000




[HAL]

# The run script first uses halcmd to execute any HALFILE
# files, and then to execute any individual HALCMD commands.

# list of hal config files to run through halcmd
# files are executed in the order in which they appear

HALFILE =		TAZ_5_CRAMPS.hal

# list of halcmd commands to execute
# commands are executed in the order in which they appear
#HALCMD =               save neta

POSTGUI_HALFILE =       3D.postgui.hal


[TRAJ]

# TP params
ARC_BLEND_ENABLE =             1
ARC_BLEND_FALLBACK_ENABLE =    0
ARC_BLEND_OPTIMIZATION_DEPTH = 70
ARC_BLEND_GAP_CYCLES =         4
ARC_BLEND_RAMP_FREQ =          20

AXES =                         4
COORDINATES =                  X Y Z A
LINEAR_UNITS =                 mm
ANGULAR_UNITS =                degree
TIME_UNITS =                   s
CYCLE_TIME =                   0.010
# FIXME need tuning
# Jog speed, mm/S
 # fm. Arcus config
DEFAULT_VELOCITY =             80.0
# Jog accel, mm/S/S
 # LulzBot X axis max accel
DEFAULT_ACCELERATION =         9000.0
# Max velocity for any coordinated move, mm/S
 # fm. Arcus config
#MAX_VELOCITY =                 80.0
 # Hypot. of XYZ max vel.
MAX_VELOCITY =                 1131
# Max acceleration for any coordinated move, mm/S/S
 # LulzBot X axis max accel
MAX_ACCELERATION =             9000.0





[AXIS_0]
# X axis

TYPE =              LINEAR
MAX_VELOCITY =       800.0
MAX_ACCELERATION =   9000.0
# Set Stepgen max 20% higher than the axis
STEPGEN_MAX_VEL =    960.0
STEPGEN_MAX_ACC =    10800.0

BACKLASH =           0.000

SCALE =  -100.5

MIN_LIMIT =             0.0
MAX_LIMIT =             298.0

FERROR =     1.0
MIN_FERROR = 0.25

HOME =                  0.000
HOME_OFFSET =           0.00
HOME_IGNORE_LIMITS =    YES
HOME_USE_INDEX =        NO
HOME_SEQUENCE =         0

# Homing and latch velocity for endstop switches
HOME_SEARCH_VEL =       -15.0
HOME_LATCH_VEL =        5.0

# these are in nanoseconds
DIRSETUP   =              200
DIRHOLD    =              200
STEPLEN    =              1000
STEPSPACE  =              1000




[AXIS_1]
# Y axis

TYPE =              LINEAR
MAX_VELOCITY =       800.0
MAX_ACCELERATION =   9000.0
# Set Stepgen max 20% higher than the axis
STEPGEN_MAX_VEL =    960.0
STEPGEN_MAX_ACC =    10800.0

BACKLASH =           0.000

SCALE =  100.5

MIN_LIMIT =             0.0
MAX_LIMIT =             275.0

FERROR =     1.0
MIN_FERROR = 0.25

HOME =                  0.000
HOME_OFFSET =           0.00
HOME_IGNORE_LIMITS =    YES
HOME_USE_INDEX =        NO
HOME_SEQUENCE =         0

# Set to zero if you don't have physical home/limit switches
# Set to the desired homing and latch velocity if you have switches
# See: https://github.com/machinekit/machinekit-docs
HOME_SEARCH_VEL =       -15.0
HOME_LATCH_VEL =        5.0

# these are in nanoseconds
DIRSETUP   =              200
DIRHOLD    =              200
STEPLEN    =              1000
STEPSPACE  =              1000




[AXIS_2]
# Z axis (left + right motors)

TYPE =              LINEAR
MAX_VELOCITY =      8.0
MAX_ACCELERATION =  100.0
# Set Stepgen max 20% higher than the axis
STEPGEN_MAX_VEL =    9.6
STEPGEN_MAX_ACC =    120.0

BACKLASH =           0.000

# Which is it?  800 according to pics of LCD display; 1600 according
# to Configuration.h
# SCALE = 800
SCALE = -1600

MIN_LIMIT =             0.0
MAX_LIMIT =             250.0

FERROR =     1.0
MIN_FERROR = 0.25

HOME =                  0.000
HOME_OFFSET =           0.00
HOME_IGNORE_LIMITS =    YES
HOME_USE_INDEX =        NO
HOME_SEQUENCE =         0

# Set to zero if you don't have physical home/limit switches
# Set to the desired homing and latch velocity if you have switches
# See: https://github.com/machinekit/machinekit-docs
HOME_SEARCH_VEL =       -15.0
HOME_LATCH_VEL =        5.0

# these are in nanoseconds
DIRSETUP   =              200
DIRHOLD    =              200
STEPLEN    =              1000
STEPSPACE  =              1000




[AXIS_3]
# Extruders
#
# Dual extruders will be multiplexed in HAL
# https://groups.google.com/d/msg/machinekit/Q4Cg4HMkvAU/oydSt1FqAgoJ

TYPE = ANGULAR
MAX_VELOCITY = 50
MAX_ACCELERATION = 10000.0
# Set Stepgen max 20% higher than the axis
STEPGEN_MAX_VEL = 60.0
STEPGEN_MAX_ACC = 12000.0

BACKLASH =           0.000

SCALE = -850

MIN_LIMIT = -9999.0
MAX_LIMIT = 999999999.0

FERROR = 1.0
MIN_FERROR = .25

HOME =                  0.000
HOME_OFFSET =           0.00
HOME_IGNORE_LIMITS =    YES
HOME_USE_INDEX =        NO
HOME_SEQUENCE =         0

# Set to zero if you don't have physical home/limit switches
# Set to the desired homing and latch velocity if you have switches
# See: https://github.com/machinekit/machinekit-docs
HOME_SEARCH_VEL =       0.0
HOME_LATCH_VEL =        0.0
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

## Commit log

2016-06-30 Update drawings
    - Updated cable lengths
    - New power harness drawing
    - Update logo and copyright
2016-07-05 Initial commit of files from Machinekit distribution
    From rev a5b67eb:
    https://github.com/machinekit/machinekit/tree/master/configs/ARM/BeagleBone/CRAMPS
    [3D.postgui.hal, CRAMPS.hal, ShuttleXpress.postgui.hal]
2016-07-05 Update hal and ini files for TAZ-5
    - Reorg HAL file into logical sections for axes, extruders and bed
    - Move limit switches, etc. into related system section
    - Fix HAL and INI file settings for TAZ hardware
    - Mirror Z motors
    - Assign correct pins
    - Enable limit switches
    - Add partial config for E2
    - Update setup.sh with same reorg, and document pins
    [CRAMPS.hal]
2016-07-06 Set bed thermistor in CRAMPS.hal
    The Hexagon Hot End thermistor [1] is a EPCOS 100k [2], not the same
    as the 24V silicone heater [3] that uses a Honeywell 100k [4], [5].
    [1]: https://www.lulzbot.com/store/parts/100k-epcos-thermistor
    [2]: http://www.epcos.com/inf/50/db/ntc_09/Glass_enc_Sensors__B57560__G560__G1560.pdf
    [3]: https://www.lulzbot.com/store/parts/24v-silicone-heater
    [4]: https://www.lulzbot.com/store/parts/100k-honeywell-axial-thermistor
    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
    [CRAMPS.hal]
2016-07-07 notes.md: add fan, M code, TAZ geom notes
    - Info about dual extruders, tool change and fan control
    - M-codes for 3D printers: doc links and MK configs
    - TAZ-5 axis geometry info
    - Test instruction updates
2016-07-07 HAL file updates
    - Dual extruder config (untested)
    - ini file `TAZ_5` section
    - Dual extruder enabled with `DUAL_EXTRUDER_ENABLE` param
    - Multiplex motors:
    - `extruder.select` signal selects extruder by number
    - multiplexes step/dir pin signals to stepgen
    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
    [CRAMPS.hal]
2016-07-07 Rename config to "TAZ_5_CRAMPS"
    - Rename hal and ini files
    - Remove ShuttleXpress config
    [ShuttleXpress.postgui.hal, TAZ_5_CRAMPS.hal]
2016-07-07 Reorg/rename files
    [3D.postgui.hal, TAZ_5_CRAMPS.hal, TAZ_5_CRAMPS.ini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]
2016-07-07 hal/ini config: add multiplexed tool head E steps
    Use independent ini parameters `[TAZ_5]E0_STEPS` and `[TAZ_5]E1_STEPS`
    [TAZ_5_CRAMPS.hal]
2016-07-08 Rename extruders to E0/E1; reorg connectors/HAL comps/etc.
    E0/E1 match existing configs and reprap; make everything easier to
    remember
    [TAZ_5_CRAMPS.hal, TAZ_5_CRAMPS.ini]
2016-07-08 Update .ini according to LulzBot Marlin configs
    Many configs added to .ini; those in `[TAZ_5]` section not yet
    plumbed; more noted in `notes.md`
    [TAZ_5_CRAMPS.ini]
2016-07-09 More hal file fixes
    - Prune GPIO pin list
    - Set `pru_period` to 5uS to fit LulzBot params
    - Fix multiplexers: MUX 2 -> float; add to servo-thread
    - Remove deprecated `newsig` statements by reorganizing
    - Reorg statements so signal values are correct after start up
    - Reformat axis sections for uniformity
    [TAZ_5_CRAMPS.hal]
2016-07-09 hal file: minor tweaks
    - Add pin numbers in hex for debugging with `halcmd show`
    - More readable names for multiplexed extruder signals
    [TAZ_5_CRAMPS.hal]
2016-07-09 ini file tweaks
    - Give E1_ESTEPS positive value to avoid errors when debugging
    - Remove obsolete comment
    [TAZ_5_CRAMPS.ini]
2016-07-09 Update tool.tbl for dual extruders
2016-07-11 notes.md: extruder motor testing and multiplexer notes
2016-07-11 Tie PWMs and PIDs to enable signal
    Using emcmot.00.enable, since extruders, etc. shouldn't be on when
    machine power is off
    E1 gets special treatment: PWM/PID not enabled unless enabled in ini
    file, too
    [TAZ_5_CRAMPS.hal]
2016-07-11 notes.md: Update bed/ext/fan FET testing notes
2016-07-11 Add E1 to VCP
    Format XML spacing
    [3D.postgui.hal]
2016-07-11 thermistor fixes
    - Fix illegal comment syntax in `3D.Temps.panel.xml`
    - Fix pin names in `3D.Temps.panel.xml`
    - Change bed thermistor type to `epcos_B57560G1104`
    [TAZ_5_CRAMPS.hal]
2016-07-11 Add configs from Daren's Arcus 3D
    - A few `TRAJ` params
    - Remappings for FDM
    https://github.com/Arcus-3d/Arcus-3D-M1
    [TAZ_5_CRAMPS.ini]
2016-07-12 ini file: fix comments
    Comments may not follow lines. :P
    [TAZ_5_CRAMPS.ini]
2016-07-12 notes.md: Info about microstepping and current limiting
2016-07-12 ini file: reverse X and Z axes
    [TAZ_5_CRAMPS.ini]
